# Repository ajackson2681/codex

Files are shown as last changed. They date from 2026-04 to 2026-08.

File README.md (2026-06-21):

# Codex

The Codex is an attempt at an open-source, distraction-free writing device inspired somewhat by the AlphaSmart Neo (at least the display was). The Codex pairs a 40x4 character LCD with USB HID keyboard support, and SD card storage. For a more in-depth summary/breakdown, you can visit the page I have on my website: [Codex Web Page](https://adamjackson.dev/codex.html).

---

## Project Status

Codex is under active development. Current state:

**Working:**
- [x] LCD driver
  - Originally used a derivation of the Arduino LiquidCrystal library (noted below under [Libraries Used](#libraries-used) and [Acknowledgements](#acknowledgments)). I have since written a custom one from the ground up specific for this project.
- [x] USB HID keyboard input via TinyUSB
- [x] Gap buffer with insert/delete/backspace
- [x] Character, word, line, frame, and document navigation
- [x] Frame buffer rendering (LCD stays in sync with cursor position)
- [x] SD card read/write (FatFs via [no-OS-FatFS-SD-SPI-RPi-Pico](https://github.com/carlk3/no-OS-FatFS-SD-SPI-RPi-Pico))
- [x] Document save/load
- [x] File selection on boot
- [x] Tab handling (inserted as two spaces)
- [x] Home/End at line, frame, and document scope
- [x] Card detect

**In progress / planned:**
- [ ] Keyboard shortcut finalization
- [ ] Save new document/give file name
- [ ] PWM backlight brightness control (potentiometer on one of the analog pins + transistor)
- [ ] Rev 2+ PCB: LiPo + boost converter, switchable external/battery power input, finalized sockets for ribbon cables/harnesses
- [ ] Final Enclosure (currently a wedge shape)
- [ ] Documentation: build guide, BOM, update procedure, etc.

**Maybes**
- [ ] Ability to change file after startup

**Explicitly out of scope (for now):**
- Text selection / clipboard
- Undo/redo
- Rich text or formatting of any kind

---

## Hardware

### Bill of Materials (high level)

| Component | Notes |
|---|---|
| Raspberry Pi Pico (RP2040) | Mounted via socket currently, likely castellated edge pads on the final PCB |
| 40x4 ST7066U character LCD | Dual controller (EN1/EN2), 4-bit mode |
| USB OTG converter | USB port for keyboard |
| SD card socket | SPI mode |
| Slide potentiometers (x2) | Contrast (to LCD V0) and brightness (to analog GPIO) |
| BC547 NPN transistor | PWM backlight switching |
| TP61090 boost converter | LiPo → 5V (Rev 2+) |
| MCP73871 charge controller | LiPo charge circuit (Rev 2+) |
| L7805 linear regulator | Bench/external power path (Rev0-Rev2, won't be on Rev3) |
| SPDT switch | Selects external 5V vs. LiPo/boost power source (Rev2 only), acts as power switch (Rev0 & Rev1) |
| LiPo cell | (Rev 2+) |

### PCB Revisions

| Rev | Purpose | Status |
|---|---|---|
| **Breadboard** | Initial validation: LCD, USB host, SD card | Done | 
| **Rev 0** | First PCB, puts the breadboard on a dedicated PCB, adds a power switch, adds filtering capacitors | Done |
| **Rev 1** | Fixes mistakes from Rev0. Sill uses socketed footprints for SD card and Pico. Adds breakout pins for contrast/brightness potentiometers, adds PWM backlight transistor. | Validating |
| **Rev 2** | Dedicated SD card slot, finalized sockets for IDC, potentiometers, and LED power. Pico footprint will allow sockets _or_ solder directly via castellated holes. 5v linear regulator will remain, with an optional switch for swapping to using a 5v direct power source (planned as a Powerboost 1000 module). | Designing |
| **Rev 3** | Removal of 5v linear regulator. Move to all SMD components for assembly by fab house. | Planned |
| **???** | Anything beyond Rev3 will only happen if I make dumb mistakes (and I probably will).

## Firmware

Built with the **Raspberry Pi Pico SDK**

### Libraries used

- Originally used a derivation of [LiquidCrystal440](https://github.com/jurs/liquidcrystal440), which is in turn a derivation of the [Original Arduino Library](https://github.com/arduino-libraries/LiquidCrystal).
  - Now uses a driver that is purpose-written for this device 
- **TinyUSB** - USB HID host
- **no-OS-FatFS-SD-SPI-RPi-Pico** - SD card / FAT filesystem (submodule)

### Recovery

If a firmware update fails or the device won't boot, hold **BOOTSEL** while connecting the Pico to a computer via USB. It will appear as a USB mass storage device. Then drag and drop a known-good `.uf2` to restore it. This is a hardware bootloader built into the RP2040 and cannot be bricked by firmware alone.

---

## Enclosure

Designed in FreeCAD. It has a sort of wedge factor with the 40x4 LCD forming most of the angled top face. Slide potentiometers for brightness and contrast are mounted on the front, with the the keyboard USB port and SD card slot to the right of those. FCStd files are located `3dmodels/` (I'm just committing the whole blob since I don't really know a better way to do it for freecad files in git).

enclosure

---

## Keyboard Compatibility

The Codex _should_ work with any standard USB HID keyboard, both wired or via a wireless USB dongle. The Codex does **not** support bluetooth keyboards.

### Recommended

For a compact keyboard, a 65% or 75% layout is recommended for dedicated Home/End/Page Up/Page Down/Arrow keys without needing Fn combinations. Otherwise, pretty much whatever you're most comfortable with. I use an Epomaker TH80SE, which is a 75% keyboard. However, that doesn't have a dedicated "End" key (it's FN+PgDown). Something like the [Epomaker x Aula F65](https://epomaker.com/products/epomaker-aula-f65) or [Epomaker x Aula F75](https://epomaker.com/products/epomaker-aula-f75) could maybe be good choices that include all the buttons.

---

## Keyboard Shortcuts (WIP)

| Shortcut | Primary Action | Secondary Action
|---|---|---|
| Arrow keys | Move cursor (character / line) | |
| Ctrl + ←/→ | Move by word | |
| Ctrl + ↑/↓ | Jump to start/end of frame | Shift view by one full frame if at frame boundaries |
| Page Up/Page Down | Shift view by one full frame | |
| Home / End | Start/end of current line | |
| Ctrl + Home/End | Jump to start/end of current frame | |
| Ctrl + Shift + Home/End | Jump to start/end of document | |
| Tab | Insert two spaces | |
| Ctrl + S | Save current document to SD card | |
| Ctrl + Shift + I | Open document info (filename, size, etc) | |

---

## License

The Codex uses a split-license approach:

- All non-third-party code: **GPL v3**
- Hardware (`pcb/`) and Enclosures (`3dmodels/`): **CERN-OHL-S v2**

All third-party libraries retain their original licensing:

- TinyUSB: **MIT**
- no-OS-FatFS-SD-SPI-RPi-Pico **Apache 2.0**

See the `LICENSE` file in each directory for full text.

---

## Acknowledgments

- [LiquidCrystal](https://github.com/arduino-libraries/LiquidCrystal) original LCD library for Arduino, modified by jurs to support 40x4 displays
- [LiquidCrystal440](https://github.com/jurs/liquidcrystal440) modification of the original LiquidCrystal library by jurs, and that this project uses with small modifications.
- [no-OS-FatFS-SD-SPI-RPi-Pico](https://github.com/carlk3/no-OS-FatFS-SD-SPI-RPi-Pico)
  by carlk3
- [TinyUSB](https://github.com/hathach/tinyusb) USB HID stack
- The AlphaSmart Neo, for the original inspiration (sort of)
- The [r/writerdeck](https://reddit.com/r/writerdeck) community

---

## Contributing

The Codex is a work in progress and a personal project, but issues, ideas, and pull requests are welcome. If you build one, I'd love to hear about it.

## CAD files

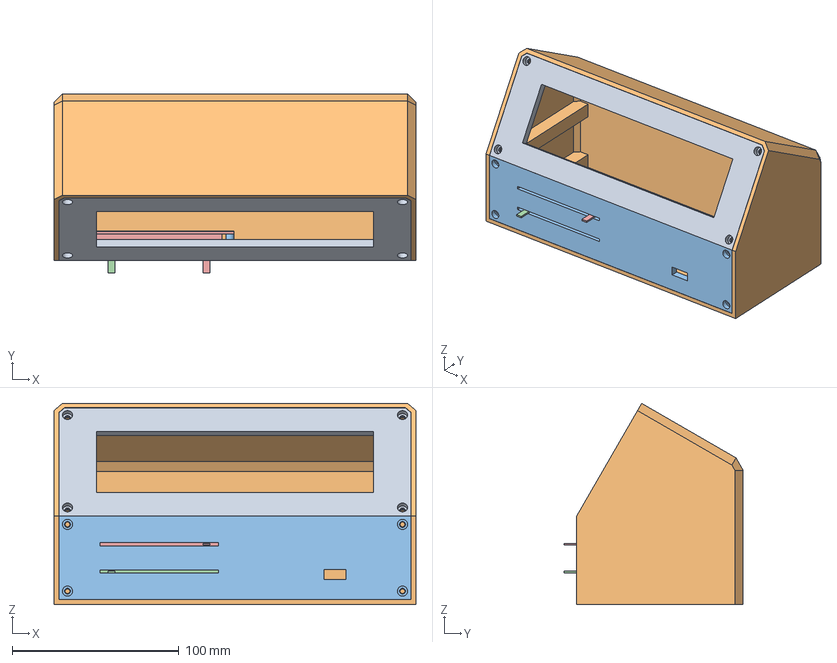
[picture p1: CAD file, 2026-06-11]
3dmodel/codex-prototype.FCStd
217.2 x 107.7 x 120.7 mm
proto_bezel
protoshell
protofront

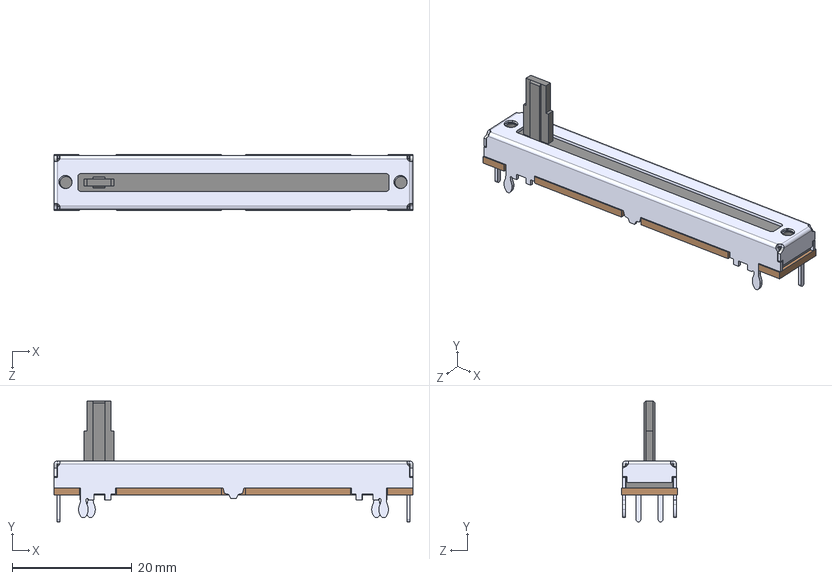
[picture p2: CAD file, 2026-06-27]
pcb/pot_module/PTA4543_2010CPB103/PTA4543-2010CPB103.step
60.0 x 20.2 x 9.40 mm

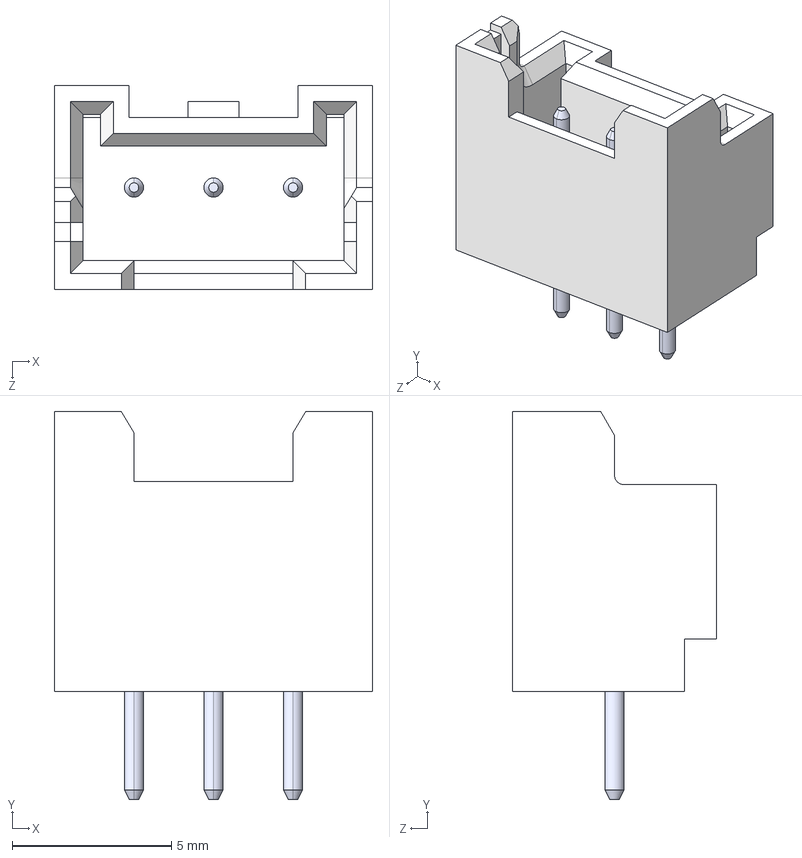
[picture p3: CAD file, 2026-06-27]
pcb/pot_module/XA_socket_3pin.STEP
10.0 x 12.2 x 6.40 mm

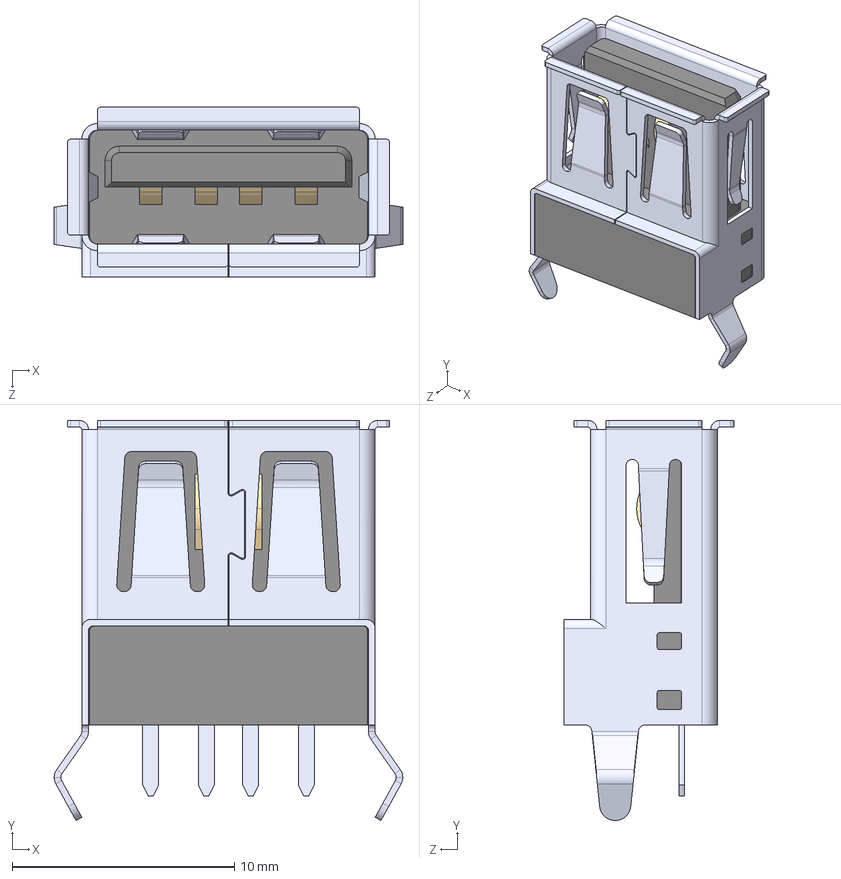
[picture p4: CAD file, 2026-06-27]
pcb/usb_daughter/USB_A1VSB6/USB-A1VSB6.step
15.7 x 18.0 x 7.64 mm

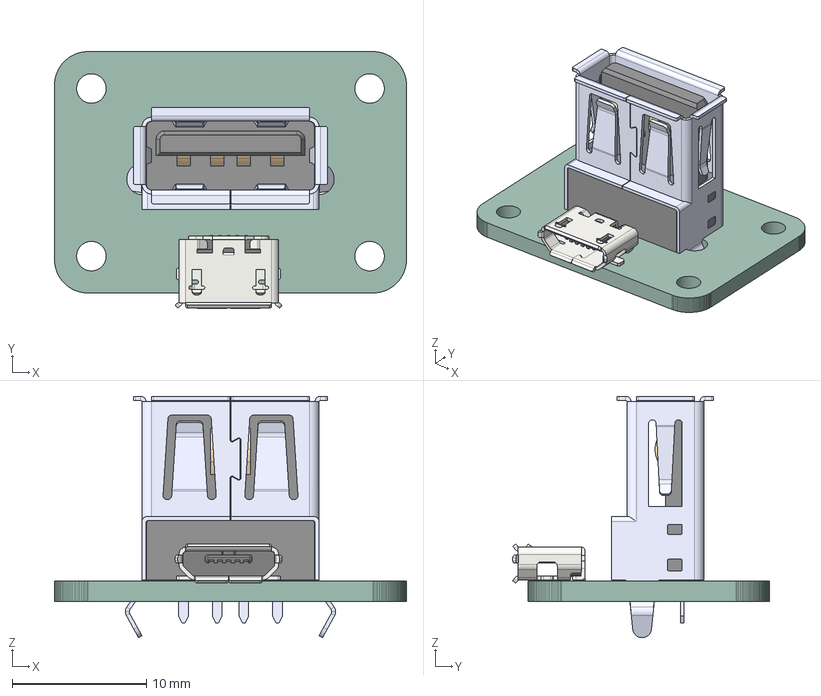
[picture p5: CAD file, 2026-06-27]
pcb/usb_daughter/usb_daughter.step
26.2 x 19.1 x 18.0 mm
USB-A1VSB6
USB_Micro-B_Molex_47346-0001
usb_daughter_PCB

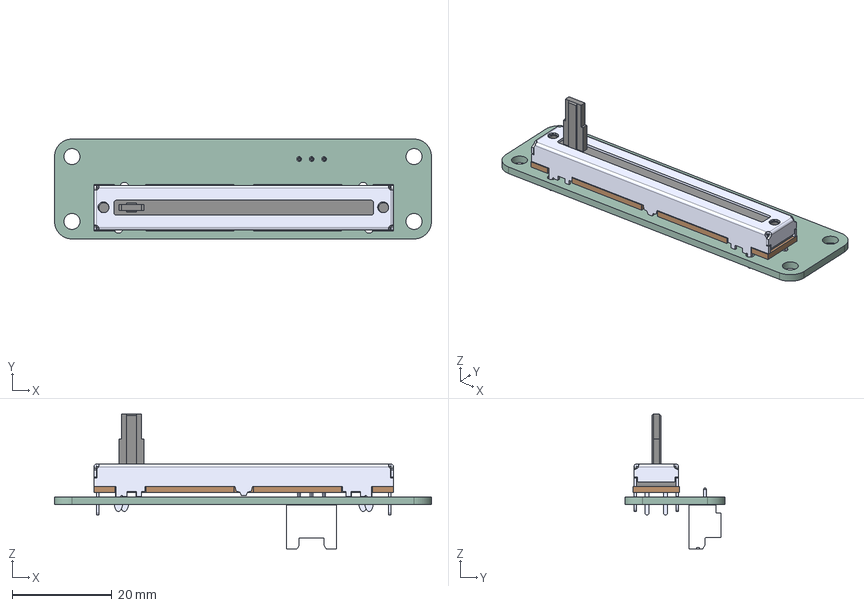
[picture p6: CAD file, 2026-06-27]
pcb/pot_module/pcb.step
75.5 x 20.0 x 27.0 mm
45310CP
B03B-XASK-1(LF)(SN)
potentiometer_PCB

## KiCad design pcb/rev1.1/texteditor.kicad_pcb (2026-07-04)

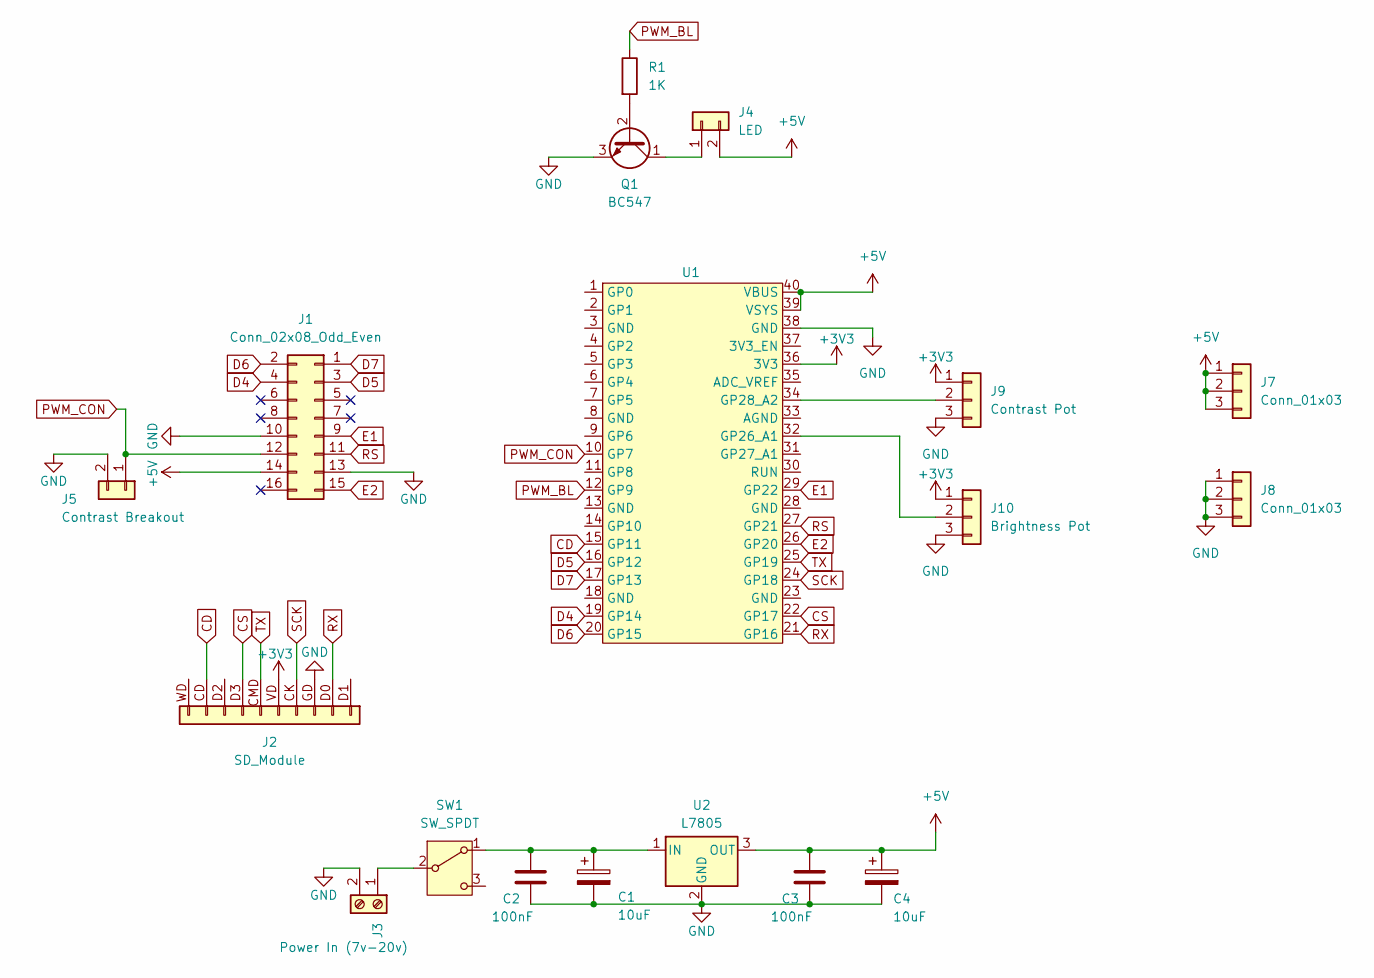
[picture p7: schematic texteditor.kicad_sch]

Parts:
C1, C4: 10uF; C_Radial_D4.0mm_H5.0mm_P1.50mm
C2, C3: 100nF; C_Disc_D4.7mm_W2.5mm_P5.00mm
J1: Conn_02x08_Odd_Even; pico_idc_connector
J2: SD_Module
J3: Power In (7v-20v); TerminalBlock_Phoenix_MKDS-1,5-2-5.08_1x02_P5.08mm_Horizont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
J4: LED; PinSocket_1x02_P2.54mm_Vertical
J5: Contrast Breakout; PinSocket_1x02_P2.54mm_Vertical
J7, J8: Conn_01x03; PinHeader_1x03_P2.54mm_Vertical
J9: Contrast Pot; PinHeader_1x03_P2.54mm_Vertical
J10: Brightness Pot; PinHeader_1x03_P2.54mm_Vertical
Q1: BC547; TO-92_Inline
R1: 1K; R_Axial_DIN0204_L3.6mm_D1.6mm_P7.62mm_Horizontal
SW1: SW_SPDT; PinHeader_1x03_P2.54mm_Vertical
U1: pico_2x20
U2: L7805; PinSocket_1x03_P2.54mm_Vertical

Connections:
+3V3: J2.VD (Pin_5), J9.1, J10.1, U1.36 (3V3)
+5V: C3.1, C4.1, J1.14, J4.2, J7.1, J7.2, J7.3, U1.39 (VSYS), U1.40 (VBUS), U2.3 (OUT)
CD: J2.CD (Pin_9), U1.15 (GP11)
CS: J2.D3 (Pin_7), U1.22 (GP17)
D4: J1.4, U1.19 (GP14)
D5: J1.3, U1.16 (GP12)
D6: J1.2, U1.20 (GP15)
D7: J1.1, U1.17 (GP13)
E1: J1.9, U1.29 (GP22)
E2: J1.15, U1.26 (GP20)
GND: C1.2, C2.2, C3.2, C4.2, J1.10, J1.13, J2.GD (Pin_3), J3.2, J5.2, J8.1, J8.2, J8.3, J9.3, J10.3, Q1.3 (E), U1.38 (GND), U2.2 (GND)
unnamed: J3.1, SW1.2 (B)
unnamed: J4.1, Q1.1 (C)
unnamed: J9.2, U1.34 (GP28_A2)
unnamed: J10.2, U1.32 (GP26_A1)
unnamed: Q1.2 (B), R1.2
unnamed: C1.1, C2.1, SW1.1 (A), U2.1 (IN)
PWM_BL: R1.1, U1.12 (GP9)
PWM_CON: J1.12, J5.1, U1.10 (GP7)
RS: J1.11, U1.27 (GP21)
RX: J2.D0 (Pin_2), U1.21 (GP16)
SCK: J2.CK (Pin_4), U1.24 (GP18)
TX: J2.CMD (Pin_6), U1.25 (GP19)

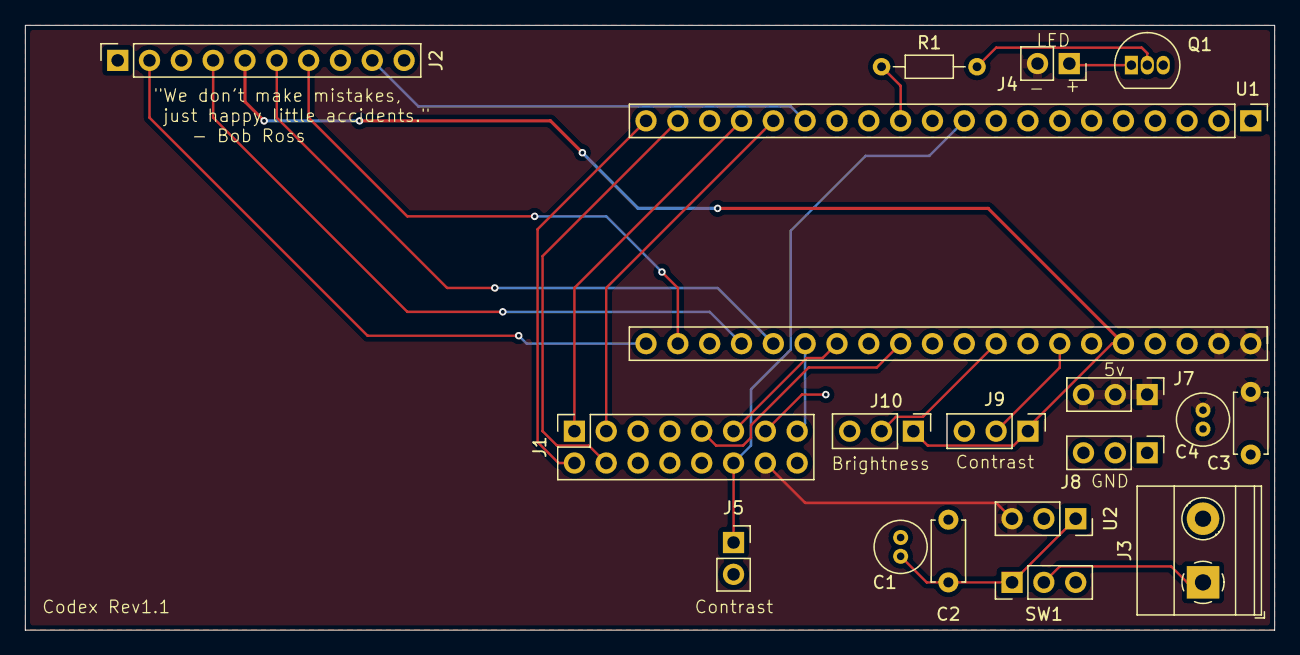
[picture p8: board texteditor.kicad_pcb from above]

Board: 2 copper layers, 99.7 x 48.3 mm, 18 parts (0 on the bottom side), 23 nets.

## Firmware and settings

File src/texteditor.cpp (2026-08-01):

#include <stdio.h>
#include <functional>

#include "pico/stdlib.h"
#include "bsp/board_api.h"
#include "tusb.h"

#include "GapBuffer.hpp"
#include "Globals.hpp"
#include "FileSystem.hpp"
#include "Config.hpp"
#include "Keyboard.hpp"
#include "Version.hpp"
#include "SystemState.hpp"

void tuh_mount_cb(uint8_t dev_addr) {}

void tuh_umount_cb(uint8_t dev_addr) {}

void initialize()
{
    FileSystem::TryLoadFile();
    SystemState::set(State::WRITING);
}

void selectDocument()
{
    lcd.setCursorPos(0,0);
    
    // skip to initialization if the file system isn't mounted
    if (!FileSystem::Mounted()) {
        SystemState::set(State::INITIALIZATION);
        return;
    }

    // loads any available file names. Only does this once, subsequent calls
    // do nothing
    FileSystem::EnumerateFiles();
    
    if (!FileSystem::HasFiles()) {
        SystemState::set(State::SET_DOC_NAME);
        return;
    }
    
    if (FileSystem::SelectionChanged()) {    
        lcd.clear();

        FileSystem::ForEachVisibleFile([](const std::string& file, int index) {
            if (index == FileSystem::GetSelectedIndex()) {
                lcd.write(CustomChar::RIGHT_ARROW);
                lcd.write(" ");
            } 
            else {
                lcd.write("  ");
            }
            lcd.write(file + "\n");
        });
    }
}

void setDocumentName()
{
    if (scratchBuffer.isStale()) {
        lcd.write("Document Name:\n");
        auto b = scratchBuffer.getVisibleFrame();
        
        lcd.setCursorPos(1,0);
    
        for (int i = 0; i < ROW_COUNT - 1; i++) { // only will have 3 lines available for this
            lcd.setCursorPos(i+1, 0);
            for (int j = 0; j < COL_COUNT; j++) {
                char c = b[i][j];
    
                switch (c) {
                    case '\n':
                    case '\r':
                    case '\0':
                        lcd.write(' ');
                        break;
                    default:
                        lcd.write(c);
                        break;
                }
            }
        }
    }

    int row,col;
    scratchBuffer.getCursorPos(row,col);
    // the cursor is on the second row, so we need to add 1 to the row value
    lcd.setCursorPos(row+1,col);
}

void renderScreen()
{    
    if (writerBuffer.isStale()) {
        auto b = writerBuffer.getVisibleFrame();
        
        for (int i = 0; i < ROW_COUNT; i++) {
            lcd.setCursorPos(i, 0);
            for (int j = 0; j < COL_COUNT; j++) {
                char c = b[i][j];
                switch (c) {
                    case '\n':
                    case '\r':
                    case '\0':
                        lcd.write(' ');
                        break;
                    default:
                        lcd.write(c);
                        break;
                }
            }
        }

        int row,col;
        writerBuffer.getCursorPos(row,col);
        lcd.setCursorPos(row,col);
    }
    else if (writerBuffer.cursorMoved()) {
        int row,col;
        writerBuffer.getCursorPos(row,col);
        lcd.setCursorPos(row,col);
    }

}

void setup()
{
    stdio_init_all();

    // init host stack on configured roothub port
    tuh_init(BOARD_TUH_RHPORT);
    
    if (board_init_after_tusb) {
        board_init_after_tusb();
    }

    gpio_init(CD_PIN);
    gpio_set_dir(CD_PIN, GPIO_IN);
    gpio_pull_up(CD_PIN);
}

int main()
{
    setup();

    lcd.initialize();
    lcd.enableCursor();

    while (true) {
        tuh_task();
        FileSystem::Check();

        switch (SystemState::get()) {
            case State::STARTUP:
                if (FileSystem::Mounted()) {
                    SystemState::set(State::STARTUP_CARD_DETECTED);
                }
                else {
                    SystemState::set(State::STARTUP_NO_CARD_DETECTED);
                }
                break;
            case State::STARTUP_CARD_DETECTED:
                if (!FileSystem::Mounted()) {
                    SystemState::set(State::STARTUP_NO_CARD_DETECTED);
                }
                break;
            case State::STARTUP_NO_CARD_DETECTED:
                if (FileSystem::Mounted()) {
                    SystemState::set(State::STARTUP_CARD_DETECTED);
                }
                break;
            case State::DOCUMENT_SELECTION: 
                selectDocument();
                break;
            case State::SET_DOC_NAME:
                setDocumentName();
                break;
            case State::INITIALIZATION:
                initialize();
                break;
            case State::WRITING:
                renderScreen();
                break;
            default:
                break;
        }
    } 
}

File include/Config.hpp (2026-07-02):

#pragma once

#include <string>

#define BOARD_REV 1

#if BOARD_REV == 0

#define RS_PIN 21

#define D7_PIN 13
#define D6_PIN 15
#define D5_PIN 12
#define D4_PIN 14

#define E1_PIN 22
#define E2_PIN 20

#define CD_PIN 26

#elif BOARD_REV == 1

#define RS_PIN 21

#define D7_PIN 13
#define D6_PIN 15
#define D5_PIN 12
#define D4_PIN 14

#define E1_PIN 22
#define E2_PIN 20

#define CD_PIN 11

#endif

#define COL_COUNT 40
#define ROW_COUNT 4
#define MAX_FILE_NAME_LENGTH 120

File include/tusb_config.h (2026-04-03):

// #ifndef _TUSB_CONFIG_H_
// #define _TUSB_CONFIG_H_

// #define CFG_TUSB_RHPORT0_MODE   OPT_MODE_HOST
// #define CFG_TUH_HID             4    // max HID devices
// #define CFG_TUH_ENUMERATION_BUFSIZE 256

// #endif

/*
 * The MIT License (MIT)
 *
 * Copyright (c) 2019 Ha Thach (tinyusb.org)
 *
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
 */

#ifndef _TUSB_CONFIG_H_
#define _TUSB_CONFIG_H_

#ifdef __cplusplus
 extern "C" {
#endif

//--------------------------------------------------------------------
// Common Configuration
//--------------------------------------------------------------------

// defined by compiler flags for flexibility
#ifndef CFG_TUSB_MCU
#error CFG_TUSB_MCU must be defined
#endif

#ifndef CFG_TUSB_OS
#define CFG_TUSB_OS           OPT_OS_NONE
#endif

#ifndef CFG_TUSB_DEBUG
#define CFG_TUSB_DEBUG        0
#endif

/* USB DMA on some MCUs can only access a specific SRAM region with restriction on alignment.
 * Tinyusb use follows macros to declare transferring memory so that they can be put
 * into those specific section.
 * e.g
 * - CFG_TUSB_MEM SECTION : __attribute__ (( section(".usb_ram") ))
 * - CFG_TUSB_MEM_ALIGN   : __attribute__ ((aligned(4)))
 */
#ifndef CFG_TUH_MEM_SECTION
#define CFG_TUH_MEM_SECTION
#endif

#ifndef CFG_TUH_MEM_ALIGN
#define CFG_TUH_MEM_ALIGN     __attribute__ ((aligned(4)))
#endif

//--------------------------------------------------------------------
// Host Configuration
//--------------------------------------------------------------------

// Enable Host stack
#define CFG_TUH_ENABLED       1

#if CFG_TUSB_MCU == OPT_MCU_RP2040
  // #define CFG_TUH_RPI_PIO_USB   1 // use pio-usb as host controller
  // #define CFG_TUH_MAX3421       1 // use max3421 as host controller

  // host roothub port is 1 if using either pio-usb or max3421
  #if (defined(CFG_TUH_RPI_PIO_USB) && CFG_TUH_RPI_PIO_USB) || (defined(CFG_TUH_MAX3421) && CFG_TUH_MAX3421)
    #define BOARD_TUH_RHPORT      1
  #endif
#endif

// Default is max speed that hardware controller could support with on-chip PHY
#define CFG_TUH_MAX_SPEED     BOARD_TUH_MAX_SPEED

//------------------------- Board Specific --------------------------

// RHPort number used for host can be defined by board.mk, default to port 0
#ifndef BOARD_TUH_RHPORT
#define BOARD_TUH_RHPORT      0
#endif

// RHPort max operational speed can defined by board.mk
#ifndef BOARD_TUH_MAX_SPEED
#define BOARD_TUH_MAX_SPEED   OPT_MODE_DEFAULT_SPEED
#endif

//--------------------------------------------------------------------
// Driver Configuration
//--------------------------------------------------------------------

// Size of buffer to hold descriptors and other data used for enumeration
#define CFG_TUH_ENUMERATION_BUFSIZE 256

#define CFG_TUH_HUB                 1 // number of supported hubs
#define CFG_TUH_CDC                 1 // CDC ACM
#define CFG_TUH_CDC_FTDI            1 // FTDI Serial.  FTDI is not part of CDC class, only to re-use CDC driver API
#define CFG_TUH_CDC_CP210X          1 // CP210x Serial. CP210X is not part of CDC class, only to re-use CDC driver API
#define CFG_TUH_CDC_CH34X           1 // CH340 or CH341 Serial. CH34X is not part of CDC class, only to re-use CDC driver API
#define CFG_TUH_HID                 (3*CFG_TUH_DEVICE_MAX) // typical keyboard + mouse device can have 3-4 HID interfaces
#define CFG_TUH_MSC                 1
#define CFG_TUH_VENDOR              0

// max device support (excluding hub device): 1 hub typically has 4 ports
#define CFG_TUH_DEVICE_MAX          (3*CFG_TUH_HUB + 1)

//------------- HID -------------//
#define CFG_TUH_HID_EPIN_BUFSIZE    64
#define CFG_TUH_HID_EPOUT_BUFSIZE   64

//------------- CDC -------------//

// Set Line Control state on enumeration/mounted:
// DTR ( bit 0), RTS (bit 1)
#define CFG_TUH_CDC_LINE_CONTROL_ON_ENUM    0x03

// Set Line Coding on enumeration/mounted, value for cdc_line_coding_t
// bit rate = 115200, 1 stop bit, no parity, 8 bit data width
#define CFG_TUH_CDC_LINE_CODING_ON_ENUM   { 115200, CDC_LINE_CODING_STOP_BITS_1, CDC_LINE_CODING_PARITY_NONE, 8 }


#ifdef __cplusplus
 }
#endif

#endif /* _TUSB_CONFIG_H_ */

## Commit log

2026-05-17 Upload rev0 schematic and design files
    [texteditor-B_Cu.gbr, texteditor-B_Mask.gbr, texteditor-B_Paste.gbr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]
2026-05-18 New board spin
    - Fixes E1 pin misrouted to ground
    - Rotates SD module socket so that it sits above the board correctly
    - Breaks out LCD v0 for contrast adjust
    - Adds a transistor for PWM control of LED backlight
    - Moves power switch to between power input and regulator, rather than after. Prevents the regulator from draining any attached battery when power is off
    - Adds additional 5v and GND test points
    [texteditor-B_Cu.gbr, texteditor-B_Mask.gbr, texteditor-B_Paste.gbr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]
2026-05-27 Add tab insert, Fix f_open
    [texteditor.cpp]
2026-06-07 rev0.1 -> rev1 pcb
    Finalized design since I sent it in for fabrication
    [texteditor-B_Cu.gbr, texteditor-B_Mask.gbr, texteditor-B_Paste.gbr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]
2026-06-08 Basic document selection working
    I still need to get the ability to create a new document, name it, and then load into it. I also need to figure out how to go BACK to document selection if the user wants to switch their document wit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
2026-06-11 Upload codex freecad model
    [codex-prototype.FCStd]
2026-06-20 WIP lcd driver
2026-06-20 Cursor should follow the position correctly now (I think)
    [LCD.cpp]
2026-06-20 Remove old LiquidCrystal driver
2026-06-20 Use new LCD driver in main program
2026-06-20 Combine redundant methods
    sendChar and sendCommand did essentially the same thing, just set the RS pin differently. This just combines them into one method called "sendByte" which takes a bool in the parameters for specifying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
    It also makes the delay be a default parameter, so we only need to supply that if we want a different delay than the default 40 us
2026-06-20 Fix weird lines 3 & 4 error with the LCD
    [LCD.cpp, texteditor.cpp]
2026-06-21 Implement new line insert above or below
2026-06-21 Add board rev-specific defines
2026-06-21 Fix file selection
    Also update version number and fix board defines
    technically, rev0 didn't have a CD pin, but I wired it to GPIO 26 on my board. Rev1 offiically used GPIO 11
    [Config.hpp, texteditor.cpp]
2026-06-22 Should fix the weird flickering when writing
    Unfortunately there's a new bug where on the main screen the cursor goes back up to line 2 when it should be on line 3
    [LCD.cpp, LCD.hpp]
2026-06-22 Use local references when inserting characters
    Direcly modifying the row and column did some weird stuff
2026-06-25 Add pcb for custom pot module
    [potentiometer-B_Cu.gbr, potentiometer-B_Mask.gbr, potentiometer-B_Paste.gbr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]
2026-06-25 remove step files from gitignore, and commit them
    [PTA4543-2010CPB103.step, XA_socket_3pin.STEP, pcb.step]
2026-06-25 Add USB daughter board
    I figured with the front panel being ~ 5mm thick, that I'm not going to find a suitable passthrough cable, so this daughter board uses a vertical USB-A cable to expose the USB port from the pico
    [USB-A1VSB6.step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]
2026-06-25 Rotate footprints so that the micro usb is on the bottom realtive to how the board should be oriented
    [usb_daughter-B_Cu.gbr, usb_daughter-B_Mask.gbr, usb_daughter-B_Paste.gbr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]
2026-06-27 Tweak pot module
    [potentiometer.kicad_pcb, potentiometer.kicad_sch]
2026-06-27 update fab outputs
    [potentiometer-B_Cu.gbr, potentiometer-B_Mask.gbr, potentiometer-B_Paste.gbr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]
2026-06-27 update usb fab outputs
    [usb_daughter-B_Cu.gbr, usb_daughter-B_Mask.gbr, usb_daughter-B_Paste.gbr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]
2026-07-01 Add some state transitions for if a card is inserted or removed during statup
2026-07-03 commit wip
    I need to make some tweaks including adding a second PWM pin
    [texteditor-B_Cu.gbr, texteditor-B_Mask.gbr, texteditor-B_Paste.gbr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]
2026-07-03 finish routing, update quote on silkscreen
    [texteditor.kicad_pcb]
2026-07-04 Add better headers for potentiometers
    [texteditor.kicad_pcb, texteditor.kicad_sch]
2026-07-04 commit fab files
    [texteditor-B_Cu.gbr, texteditor-B_Mask.gbr, texteditor-B_Paste.gbr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]
2026-07-17 Increase initialization time. I was seeing failure to start occasionaly
    [LCD.cpp]
2026-07-31 Fix bug where lines 2 & 3 would periodically swap
    [LCD.cpp]
2026-08-01 Try different rendering technique
    Set the cursor at the beginning of each row and then write the row.
    Then if we only move the cursor, don't re-render the whole frame
2026-08-01 Fix set doc name
    [texteditor.cpp]
